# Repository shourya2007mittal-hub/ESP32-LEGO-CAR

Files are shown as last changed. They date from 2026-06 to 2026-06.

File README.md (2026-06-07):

# ESP32-LEGO-CAR

So I made a custom ESP32 chip based Car which is based on LEGO theme. I made the PCB on Kicad and the 3D designs were made on autodesk fusion. The board encludes 16 MB flash Storage, USB-C Connector,voltage regulator , battery charging IC , and 2 motor drives. 

## Features

- Base on custom ESP32 chip
- Design Inspired by LEGO
- Includes 4 Motor gears and recharable battery.

   ### Schematic

  

 ###  PCB Design
 
 


### 3D Render






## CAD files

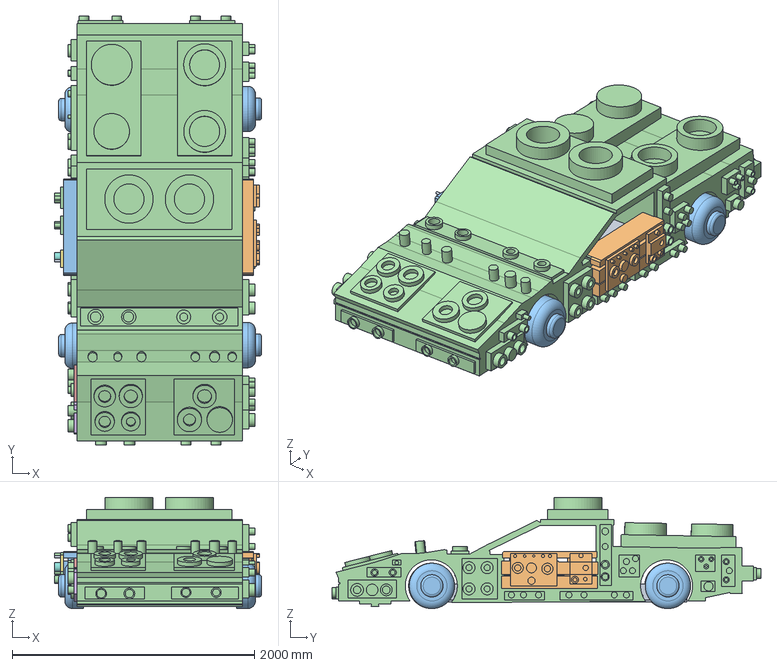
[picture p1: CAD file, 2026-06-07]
ESP32 LEGO CAR/CAD/LEGO CAR (Assembly).step
1710.0 x 3540.2 x 917.5 mm

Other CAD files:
ESP32 LEGO CAR/Production/LEGO CAR (Assembly).stl
ESP32 LEGO CAR/CAD/LEGO CAR (Assembly).f3d

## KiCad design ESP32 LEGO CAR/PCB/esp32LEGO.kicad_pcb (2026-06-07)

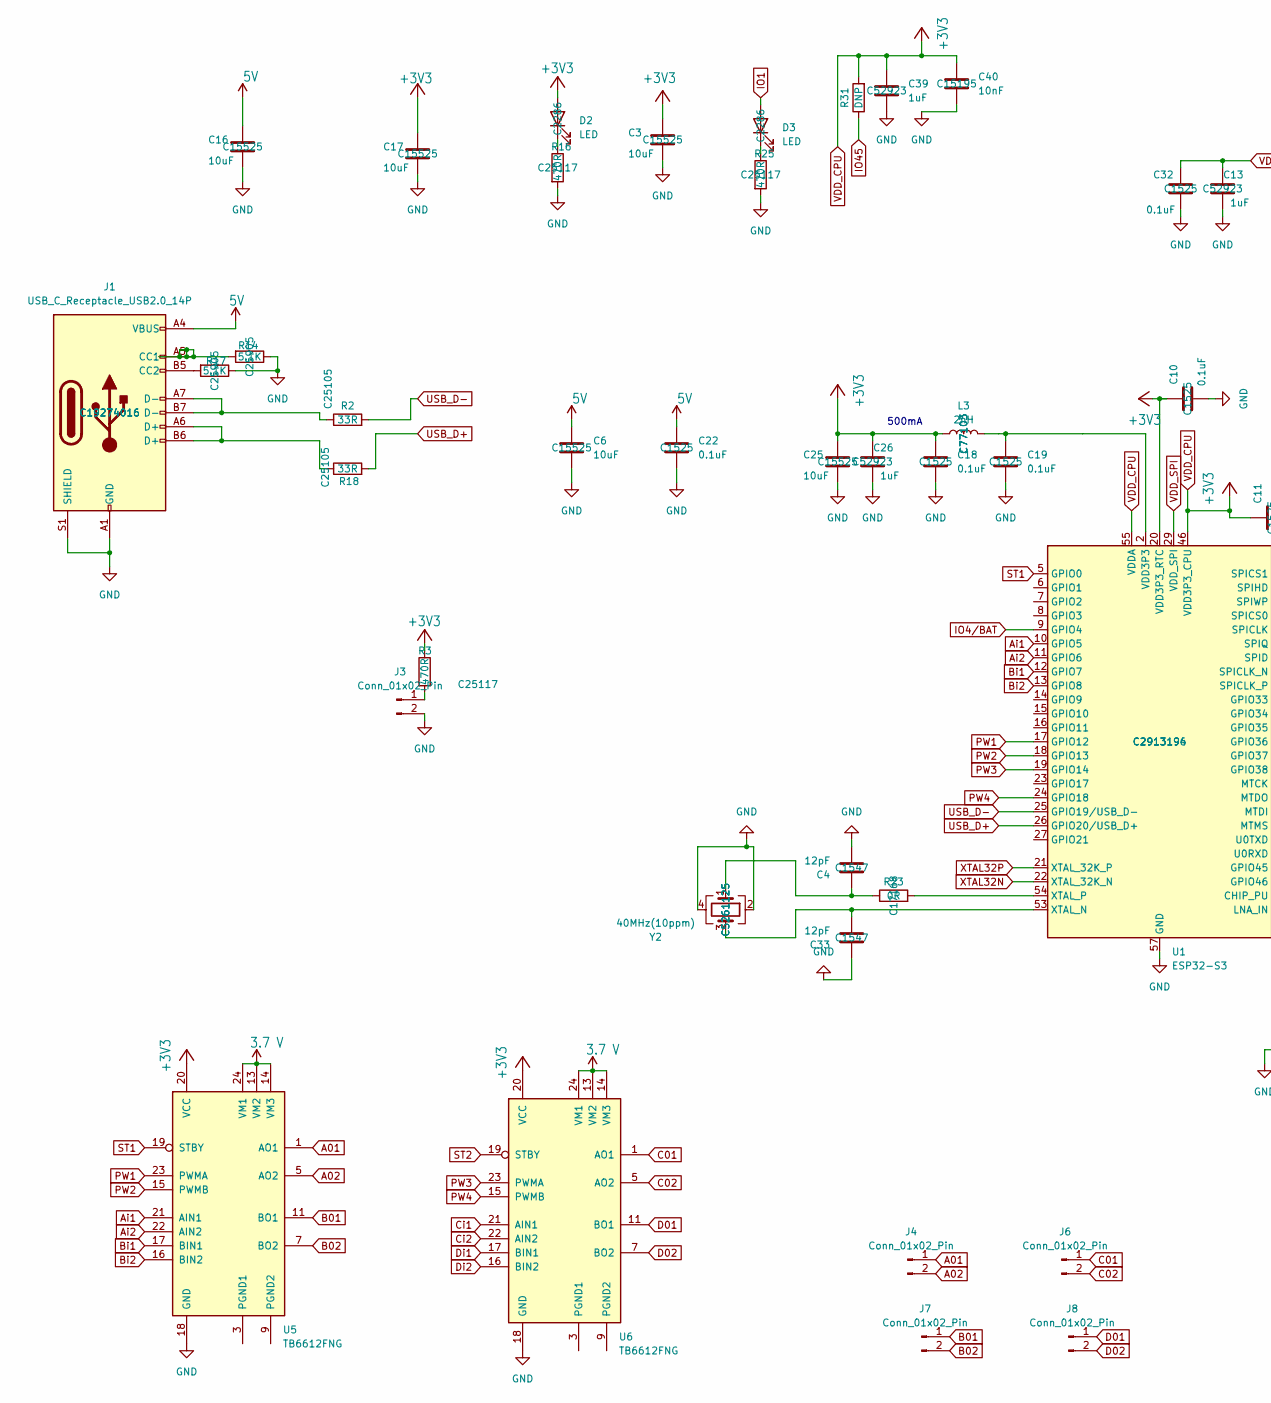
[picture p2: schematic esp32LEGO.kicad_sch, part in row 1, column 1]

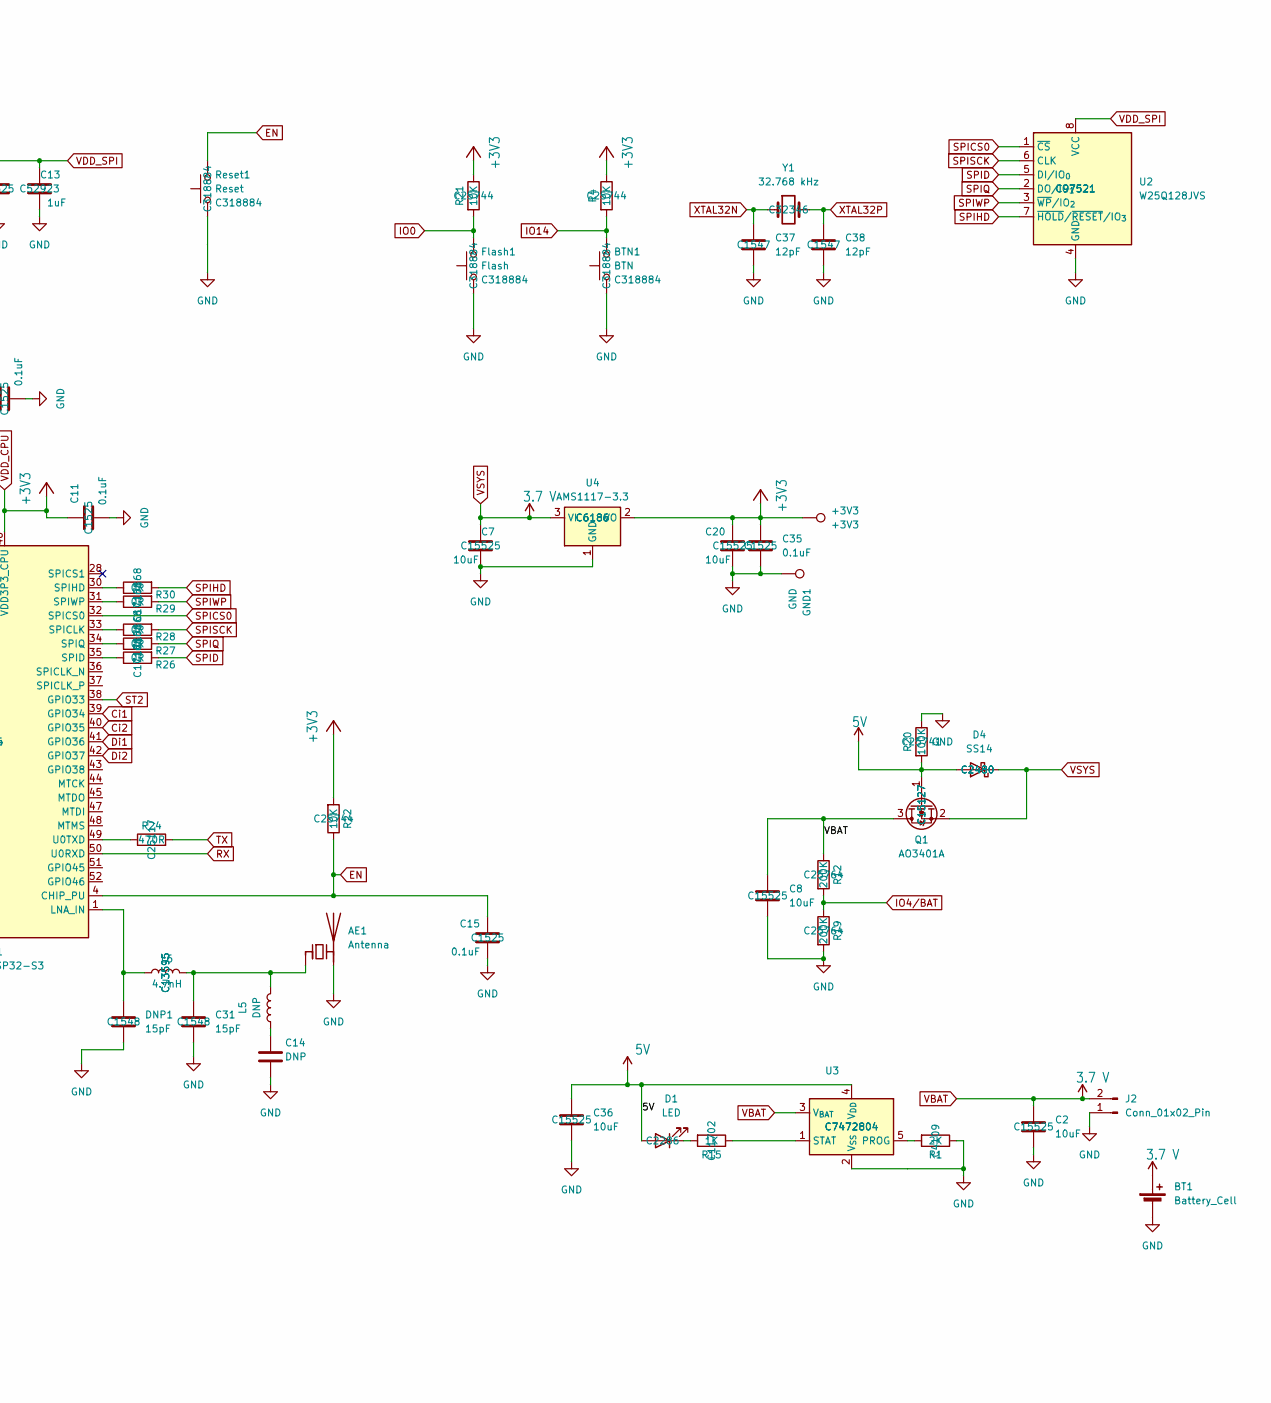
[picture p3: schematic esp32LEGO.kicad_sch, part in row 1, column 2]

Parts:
+3V3: +3V3; TestPoint_Pad_D1.0mm
AE1: Antenna; Texas_SWRA117D_2.4GHz_Left
BT1: Battery_Cell
BTN1: BTN; SW_Push_1P1T_XKB_TS-1187A; MNF PART NUMBER C318884; LCSC C318884
C2, C3, C6, C7, C8, C16, C17, C20, C25, C36: 10uF; C_0402_1005Metric; MNF PART NUMBER C15525; LCSC C15525
C4, C33, C37, C38: 12pF; C_0402_1005Metric; MNF PART NUMBER C1547; LCSC C1547
C10, C11, C15, C18, C19, C22, C32, C35: 0.1uF; C_0402_1005Metric; MNF PART NUMBER C1525; LCSC C1525
C13, C26, C39: 1uF; C_0402_1005Metric; MNF PART NUMBER C52923; LCSC C52923
C14: DNP; C_0402_1005Metric
C31: 15pF; C_0402_1005Metric; MNF PART NUMBER C1548; LCSC C1548
C40: 10nF; C_0402_1005Metric; MNF PART NUMBER C15195; LCSC C15195
D1, D2, D3: LED; LED_0603_1608Metric; MNF PART NUMBER C2286; LCSC C2286
D4: SS14; D_SMA; MNF PART NUMBER C2480; LCSC C2480
DNP1: 15pF; C_0402_1005Metric; MNF PART NUMBER C1548; LCSC C1548
Flash1: Flash; SW_Push_1P1T_XKB_TS-1187A; MNF PART NUMBER C318884; LCSC C318884
GND1: GND; TestPoint_Pad_D1.0mm
J1: USB_C_Receptacle_USB2.0_14P; USB_C_Receptacle_HCTL_HC-TYPE-C-16P-01A; MNF PART NUMBER C19274016; LCSC C19274016
J2: Conn_01x02_Pin; PinSocket_1x02_P2.54mm_Vertical
J3, J4, J6, J7, J8: Conn_01x02_Pin; AMASS_XT30U-F_1x02_P5.0mm_Vertical
L3: 2nH; L_0402_1005Metric; MNF PART NUMBER C77103; LCSC C77103
L5: DNP; L_0402_1005Metric
L6: 4.7nH; L_0402_1005Metric; MNF PART NUMBER C13595; LCSC C13595
Q1: AO3401A; SOT-23; MNF PART NUMBER C15127; LCSC C15127
R1: 2K; R_0402_1005Metric; MNF PART NUMBER C4109; LCSC C4109
R2, R18: 33R; R_0402_1005Metric; MNF PART NUMBER C25105; LCSC C25105
R3, R16, R24, R25: 470R; R_0402_1005Metric; MNF PART NUMBER C25117; LCSC C25117
R4, R21, R22: 10K; R_0402_1005Metric; MNF PART NUMBER C25744; LCSC C25744
R12, R19: 200K; R_0402_1005Metric; MNF PART NUMBER C25764; LCSC C25764
R14, R17: 5.1K; R_0402_1005Metric; MNF PART NUMBER C25905; LCSC C25905
R15: 1K; R_0402_1005Metric; MNF PART NUMBER C11702; LCSC C11702
R20: 100K; R_0402_1005Metric; MNF PART NUMBER C25741; LCSC C25741
R23, R26, R27, R28, R29, R30: 0R; R_0402_1005Metric; MNF PART NUMBER C17168; LCSC C17168
R31: DNP; R_0402_1005Metric
Reset1: Reset; SW_Push_1P1T_XKB_TS-1187A; MNF PART NUMBER C318884; LCSC C318884
U1: ESP32-S3; QFN-56-1EP_7x7mm_P0.4mm_EP4x4mm; MNF PART NUMBER C2913196; LCSC C2913194
U2: W25Q128JVS; SOIC-8_5.3x5.3mm_P1.27mm; MNF PART NUMBER C97521; LCSC C97521
U3: MCP73831-2-OT; SOT-23-5; MNF PART NUMBER C7472804; LCSC C7472804
U4: AMS1117-3.3; SOT-223-3_TabPin2; MNF PART NUMBER C6186; LCSC C6186
U5, U6: TB6612FNG; SSOP-24_5.3x8.2mm_P0.65mm
Y1: 32.768 kHz; Crystal_SMD_3215-2Pin_3.2x1.5mm; MNF PART NUMBER C32346; LCSC C32346
Y2: 40MHz(10ppm); Crystal_SMD_2520-4Pin_2.5x2.0mm; MNF PART NUMBER C5261125; LCSC C5261125

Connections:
5V: C6.1, C16.1, C22.1, C36.1, D1.2 (A), D4.2 (A), J1.A4 (VBUS), J1.A9 (VBUS), J1.B4 (VBUS), J1.B9 (VBUS), Q1.1 (G), R20.2, U3.4 (V_{DD})
A01: J4.1, U5.1 (AO1), U5.2 (AO1)
A02: J4.2, U5.5 (AO2), U5.6 (AO2)
Ai1: U1.10 (GPIO5), U5.21 (AIN1)
Ai2: U1.11 (GPIO6), U5.22 (AIN2)
B01: J7.1, U5.11 (BO1), U5.12 (BO1)
B02: J7.2, U5.7 (BO2), U5.8 (BO2)
Bi1: U1.12 (GPIO7), U5.17 (BIN1)
Bi2: U1.13 (GPIO8), U5.16 (BIN2)
C01: J6.1, U6.1 (AO1), U6.2 (AO1)
C02: J6.2, U6.5 (AO2), U6.6 (AO2)
Ci1: U1.39 (GPIO34), U6.21 (AIN1)
Ci2: U1.40 (GPIO35), U6.22 (AIN2)
D01: J8.1, U6.11 (BO1), U6.12 (BO1)
D02: J8.2, U6.7 (BO2), U6.8 (BO2)
Di1: U1.41 (GPIO36), U6.17 (BIN1)
Di2: U1.42 (GPIO37), U6.16 (BIN2)
EN: C15.1, R22.1, Reset1.2, U1.4 (CHIP_PU)
GND: AE1.2 (PCB_Trace), BT1.2 (-), BTN1.1, C2.2, C3.2, C4.2, C6.2, C7.2, C8.2, C10.2, C11.2, C13.2, C14.2, C15.2, C16.2, C17.2, C18.2, C19.2, C20.2, C22.2, C25.2, C26.2, C31.2, C32.2, C33.1, C35.2, C36.2, C37.2, C38.2, C39.2, C40.2, DNP1.2, Flash1.1, GND1.1, J1.A1 (GND), J1.A12 (GND), J1.B1 (GND), J1.B12 (GND), J1.S1 (SHIELD), J2.1, J3.2, R1.1, R14.1, R16.2, R17.1, R19.2, R20.1, R25.2, Reset1.1, U1.57 (GND), U2.4 (GND), U3.2 (V_{SS}), U4.1 (GND), U5.18 (GND), U6.18 (GND), Y2.2, Y2.4
IO0: Flash1.2, R21.2
IO1: D3.2 (A)
IO4/BAT: R12.2, R19.1, U1.9 (GPIO4)
IO14: BTN1.2, R4.2
IO45: R31.1
unnamed: AE1.1 (FEED), C31.1, L5.2, L6.2
unnamed: C4.1, R23.1, Y2.1
unnamed: C14.1, L5.1
unnamed: C19.1, L3.2, U1.2 (VDD3P3), U1.3 (VDD3P3)
unnamed: D1.1 (K), R15.2
unnamed: D2.1 (K), R16.1
unnamed: D3.1 (K), R25.1
unnamed: J1.A5 (CC1), R14.2
unnamed: J1.B5 (CC2), R17.2
unnamed: J1.A6 (D+), J1.B6 (D+), R18.1
unnamed: J1.A7 (D-), J1.B7 (D-), R2.1
unnamed: J3.1, R3.2
unnamed: DNP1.1, L6.1, U1.1 (LNA_IN)
unnamed: R28.1, U1.33 (SPICLK)
unnamed: R26.1, U1.35 (SPID)
unnamed: R30.1, U1.30 (SPIHD)
unnamed: R27.1, U1.34 (SPIQ)
unnamed: R29.1, U1.31 (SPIWP)
unnamed: R24.1, U1.49 (U0TXD)
unnamed: C33.2, U1.53 (XTAL_N), Y2.3
unnamed: R23.2, U1.54 (XTAL_P)
unnamed: R1.2, U3.5 (PROG)
unnamed: R15.1, U3.1 (STAT)
unnamed: U5.3 (PGND1), U5.4 (PGND1)
unnamed: U5.9 (PGND2), U5.10 (PGND2)
unnamed: U6.3 (PGND1), U6.4 (PGND1)
unnamed: U6.9 (PGND2), U6.10 (PGND2)
PW1: U1.17 (GPIO12), U5.23 (PWMA)
PW2: U1.18 (GPIO13), U5.15 (PWMB)
PW3: U1.19 (GPIO14), U6.23 (PWMA)
PW4: U1.24 (GPIO18), U6.15 (PWMB)
RX: U1.50 (U0RXD)
SPICS0: U1.32 (SPICS0), U2.1 (~CS)
SPID: R26.2, U2.5 (DI/IO_{0})
SPIHD: R30.2, U2.7 (~HOLD/~RESET/IO_{3})
SPIQ: R27.2, U2.2 (DO/IO_{1})
SPISCK: R28.2, U2.6 (CLK)
SPIWP: R29.2, U2.3 (~WP/IO_{2})
ST1: U1.5 (GPIO0), U5.19 (STBY)
ST2: U1.38 (GPIO33), U6.19 (STBY)
TX: R24.2
USB_D+: R18.2, U1.26 (GPIO20/USB_D+)
USB_D-: R2.2, U1.25 (GPIO19/USB_D-)
VBAT: BT1.1 (+), C2.1, C7.1, C8.1, D4.1 (K), J2.2, Q1.2 (S), Q1.3 (D), R12.1, U3.3 (V_{BAT}), U4.3 (VI), U5.13 (VM2), U5.14 (VM3), U5.24 (VM1), U6.13 (VM2), U6.14 (VM3), U6.24 (VM1)
VDD_CPU: +3V3.1, C3.1, C10.1, C11.1, C17.1, C18.1, C20.1, C25.1, C26.1, C35.1, C39.1, C40.1, D2.2 (A), L3.1, R3.1, R4.1, R21.1, R22.2, R31.2, U1.20 (VDD3P3_RTC), U1.46 (VDD3P3_CPU), U1.55 (VDDA), U1.56 (VDDA), U4.2 (VO), U5.20 (VCC), U6.20 (VCC)
VDD_SPI: C13.1, C32.1, U1.29 (VDD_SPI), U2.8 (VCC)
XTAL32N: C37.1, U1.22 (XTAL_32K_N), Y1.1
XTAL32P: C38.1, U1.21 (XTAL_32K_P), Y1.2

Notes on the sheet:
500mA

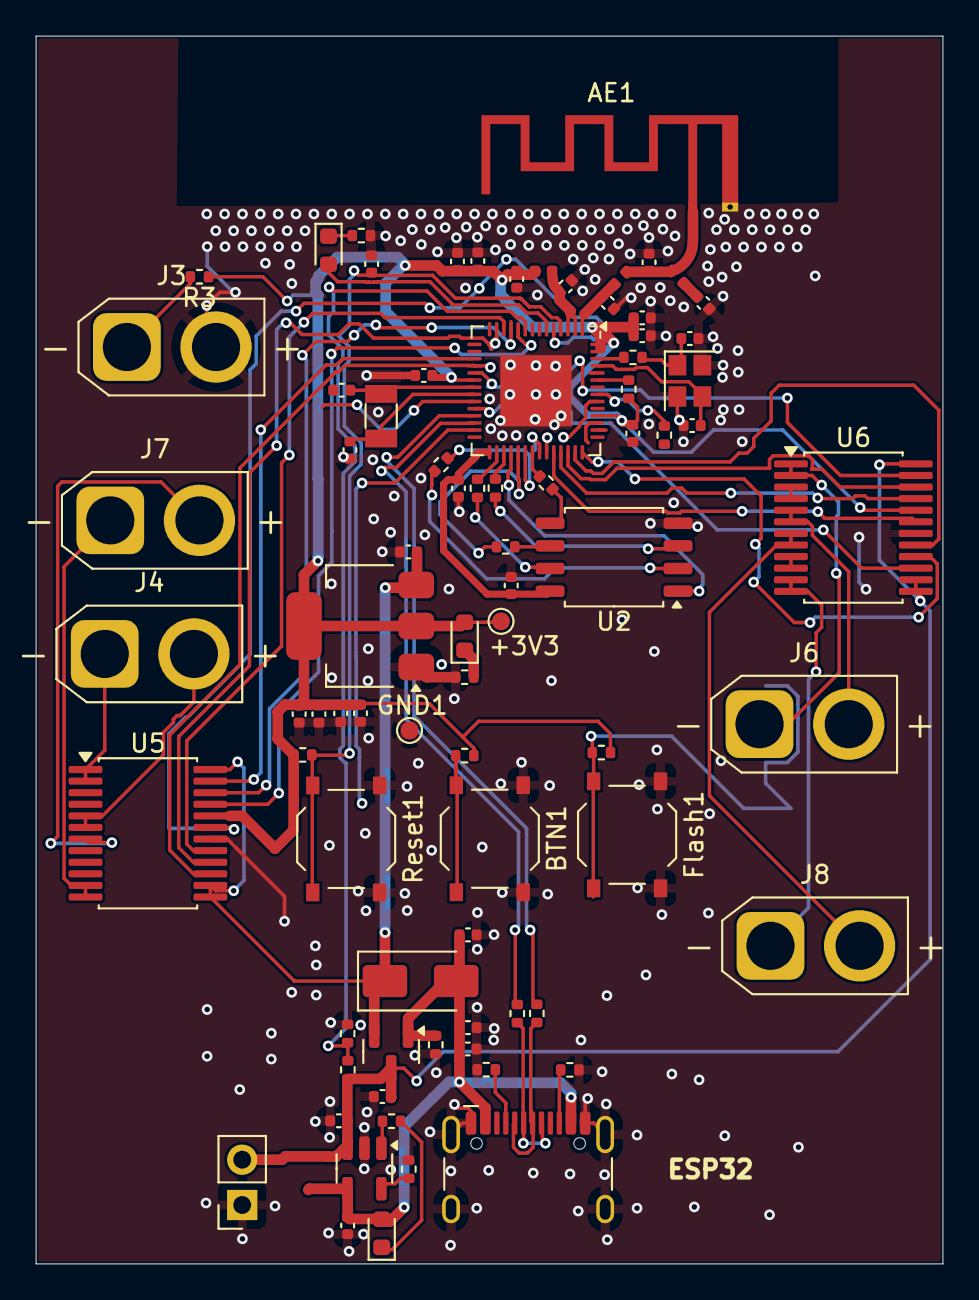
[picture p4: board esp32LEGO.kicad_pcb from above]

Board: 2 copper layers, 50.9 x 68.8 mm, 81 parts (0 on the bottom side), 68 nets.
